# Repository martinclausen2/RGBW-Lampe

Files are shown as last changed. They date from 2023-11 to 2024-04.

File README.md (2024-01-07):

# RGBW-Lampe

The "RGBW-Lampe" projects allows to create full color lighting appliances.

## Features

- Four independent LED driver channels
  - Optimal to drive RGBW LED modules.
  - Mood light mode
  - High dynamic dimming range ideal for color mixing
- Status LED to indicate power on, channel, standby, and network status
- Brightness measurement to adjust brightness at power on
- IR remote control (receiver and sender)
  -	Option to network devices
- Single rotational encoder and switch needed to control
- Embedded terminal to control settings, clock, and alarms available via WLAN
  - Connect to home automation via MQTT
  - Adjust settings via exposed terminal
- Protected electronic power switch

## Technical Features
- ARM Cortex M3 based STM32L151A microcontroller
  - EEPROM for permanent storage of settings
- ESP8266 based WLAN connectivity ESP-12
- RC5 based communication (sender and receiver)
- Four PT4115 step-down LED driver
  - PWM input
  - LED driving current up to 1A
  - Short rise time of driving current to drive LED with very low duty PWM signals needed for color mixing
- Input voltage 9 to 15 V
- High dynamic brightness measurement with low cost phototransistor SFH320
- Pin header for observing and intercepting serial communication between MCU and WLAN module
  - Debugging
  - Initial programming of WLAN module
  - Redirecting communication to / from serial port of J-LINK
- PCB prepared (not used in current software) for 
  - Acceleration sensor
  - Pin headers for extension with additional I2C devices, LCD, or LED drivers
  - EEPROM from 24CXXX series with I2C connection - currently the MCU's internal EEPROM is utilized, the EEPROM can be populated if other STM32 MCU are to be used which do not contain a EEPROM

# Design description

## Hardware

### WLAN
The low cost WLAN module ESP-12 based on the ESP8266 is used to connect to home automation, expose an interface to configure the appliance, and to obtain date and time via NTP.

### MCU
The STM32L1 series features for this application relevant features like a large number of timers, and an embedded EEPROM.

The MCU can be programmed and debugged via SWD accessible through a custom pin header, that also exposes the serial port.

### LED Driver
Color mixing requires a large dimming range, which was realized via PWM dimming. The LED driver PT4115 has a short rise time allowing to create also very short current pulses to drive the LEDs at low levels.

### Logic Power Supply
A step down voltage regulator generates 3.3 V logic supply. It needs to be capable to provide good load regulation and sufficient current for the WLAN module as well as the IR-LED.

### RC5 receiver and sender

A IR emitting diode is driven by a small MOSFET from the PWM output of a timer in the MCU to send RC5 commands.

To receive RC5 commands the output of the IR receiver is sampled at a rate of about 4.5kHz by the MCU. The power supply of the IR receiver is cut in standby mode to prevent the battery to be drained prematurely.

### Brightness Sensor

The ambient brightness is sensed via an inexpensive and broadly available phototransistor SFA 320. To enhance the dynamic range, the MCU can switch the bias current between two different levels.
The precision is fully sufficient to adjust the brightness of the power LEDs at power on and dim the status LED in standby.

## Software

### WLAN Module

The time is fetched on start and about once per day later from the NTP server.

The terminal is exposed via port 22.

## Known Limitations
- The WLAN module may lose its connection when allowing Protected Management Frames (PMF) by the WLAN access point.
  - For Fritz!Box the option is found under WLAN -> Security -> Additional Security Settings
	 - German: Leave the option "Unterstützung für geschützte Anmeldungen von WLAN-Geräten (PMF) aktivieren" **unchecked**
- The WLAN module has fixed settings. Recompilation and flashing of the ESP8266 is needed to change them.
  - MQTT (device?.h)
  - WLAN (credentials.h)
  - NTP server (device?.h)
- The WLAN module exposes the ports of terminal (22) and MQTT without any protection.
- Commands received via MQTT and updates from the NTP server are injected into the terminal communication. Commands from the terminal might be interrupted by MQTT or time updates.
- OTA updates of the STM32 are not implemented yet.
- During power on, the LED driver operate at full current for a fraction of a second.

# User Manual

The user interface is rather simplistic.

Turning the encoder increases or decreases the brightness.
The integrated push button is used to select functionality and change between on and off.
Detailed settings can be adjusted via the serial terminal.

Coming from standby a short button press switches the light on. A long button press activates the networked mode, where other compatible lighting appliances receive commands to follow on, off, and brightness settings.

When the appliance in on the short button press selects between the four individual LED strings and a mode where the brightness is modulated between the channels.

When the button is pressed, the status led previews a for a short time the next selected functionality.

Standby can be reached via a long button pressed from power on mode.

| LED Color 	| Condition | Status | 
| :--- | :--- | :--- |
| red			| | standby  |
| white			| | power on |
| blue flashing | 1 flash, pause | WLAN module booting |
| blue flashing | 3 flash, pause | No time from NTP server obtained |
| green flash	| while adjusting brightness | maximum brightness reached |
| red flash		| while adjusting brightness | minimum brightness reached |
| white flash	| pressing the button short | selected white LED channel  |
| red flash		| pressing the button short | selected red LED channel |
| blue flash	| pressing the button short | selected blue LED channel |
| green flash	| pressing the button short | selected green LED channel |
| pink flash	| pressing the button short | selected mood light mode |
| green flash	| pressing the button very long | cancel button pressed |

The white flash is actually not visible, since the LED is already shining white.

# Configuration Manual

The serial port uses the following parameter 115200 Baud rate, data site 8, parity none, stop bits 1.

This terminal is exposed via the WLAN module to the user on port 22.

The commands can be listed by sending the command `help`.

## WLAN

WLAN credentials must be set at compile time in the file `credentials.h`.

## MQTT

Broker and node name must be defined at compile time in the file `device?.h`:

	#define MQTTbroker "192.168.178.123"
	#define nodename "RGBW-Lampe1"

Topics might be freely defined at compile time in the file `device?.h`. The following section contains some examples.

The appliance publishes to different topics its status:

	#define publishtopicstatus "RGBW-Lampe/1/status"
	#define publishtopicNTP "RGBW-Lampe/1/NTP"
	#define publishtopicswitch "RGBW-Lampe/1/switch"

The appliance subscribes to two topics defined at compile time in the file `device?.h`. The names are here choosen to be independent of the device id.

### MQTT to terminal forwarder

	#define subscribetopic "RGBW-Lampe"
All data is forwarded to the terminal of the MCU. See terminal section below for details.

### Switch

	#define subscribetopicswitch "RGBW-Lampe/switch"
The commands are `on` and `off`

## Commands Terminal

The terminal is accessible at three different routes:

- Interception of the serial WLAN - MCU communication through the pin header on the PCB
- Port 22 of the WLAN module
- MQTT topic defined by `subscribetopic`

### Set Brightness

	bright [type] <-c channel_no> <-b brightness_value>

set brightness values

| Type | Description |
| :--- | :--- |
| 0 | Brightness last used before lights were switched off. |
| 1 | Minimum brightness when switched on |
| 2 | Maximum brightness any time |
| 3 | Maximum brightness when an alarm is triggered |
| 4 | PWM offset for brightness |
| 5 | Current brightness |

### Get External Brightness

	getextbright

Get the external brightness from the phototransistor

### Infrared Remote Control

	remote <-a address> <-rm receiver mode> <-sm sender mode> <-sa send address> <-sd send data>

set infrared remote parameters

| Mode | Decription |
| :--- | :--- |
| 0 | Off |
| 1 | Alarm |
| 2 | Condional |
| 3 | All |

### Set Date and Time

	time [hour] [minute] [second]

set time of RTC

	date [2 digit year] [month] [day] [w] with w weekday

set date of RTC

	timestamp

get date and time from RTC

### Alarm

	alarmschedule [alarm no] <-w weekday> <-h hour> <-m minute>

set alarm schedule

	alarmsetting <-f time to fade-in light> <-si time to signal> <-sn snooze time>

set alarm parameters
	
	alarm <-a 1 | 0> <-s alarm skip count>

trigger, reset, set alarm skip count

### Beep

	beep <-s 1 | 0> volume - <-v volume> volume level - <-vl 1 | 0>

Call without any parameters to hear a beep. Using the `-s` parameter allows to turn the acoustic signal on and off. Volume allows for a continues selection of the volume between 0 and 255. The volume level sets the range in which the volume is adjustable.

### Power

	power <-l 1 | 0>

switch light.

### Reset Settings

	reset

reset settings to factory defaults

### Status LED

	statusled [flash count]

flash status led

### Mood light

	fadelight <-f 1 | 0> time - <-t time> <-b brightness> <-mb maximum brightness>

switch and parameterize on mood light

### DebugCmd

	debug

Dummy command to absorb debug messages from host.

### Reset WLAN Module

	resetesp

Reset network controller ESP8266.

### Version

	version

show STM32 software version

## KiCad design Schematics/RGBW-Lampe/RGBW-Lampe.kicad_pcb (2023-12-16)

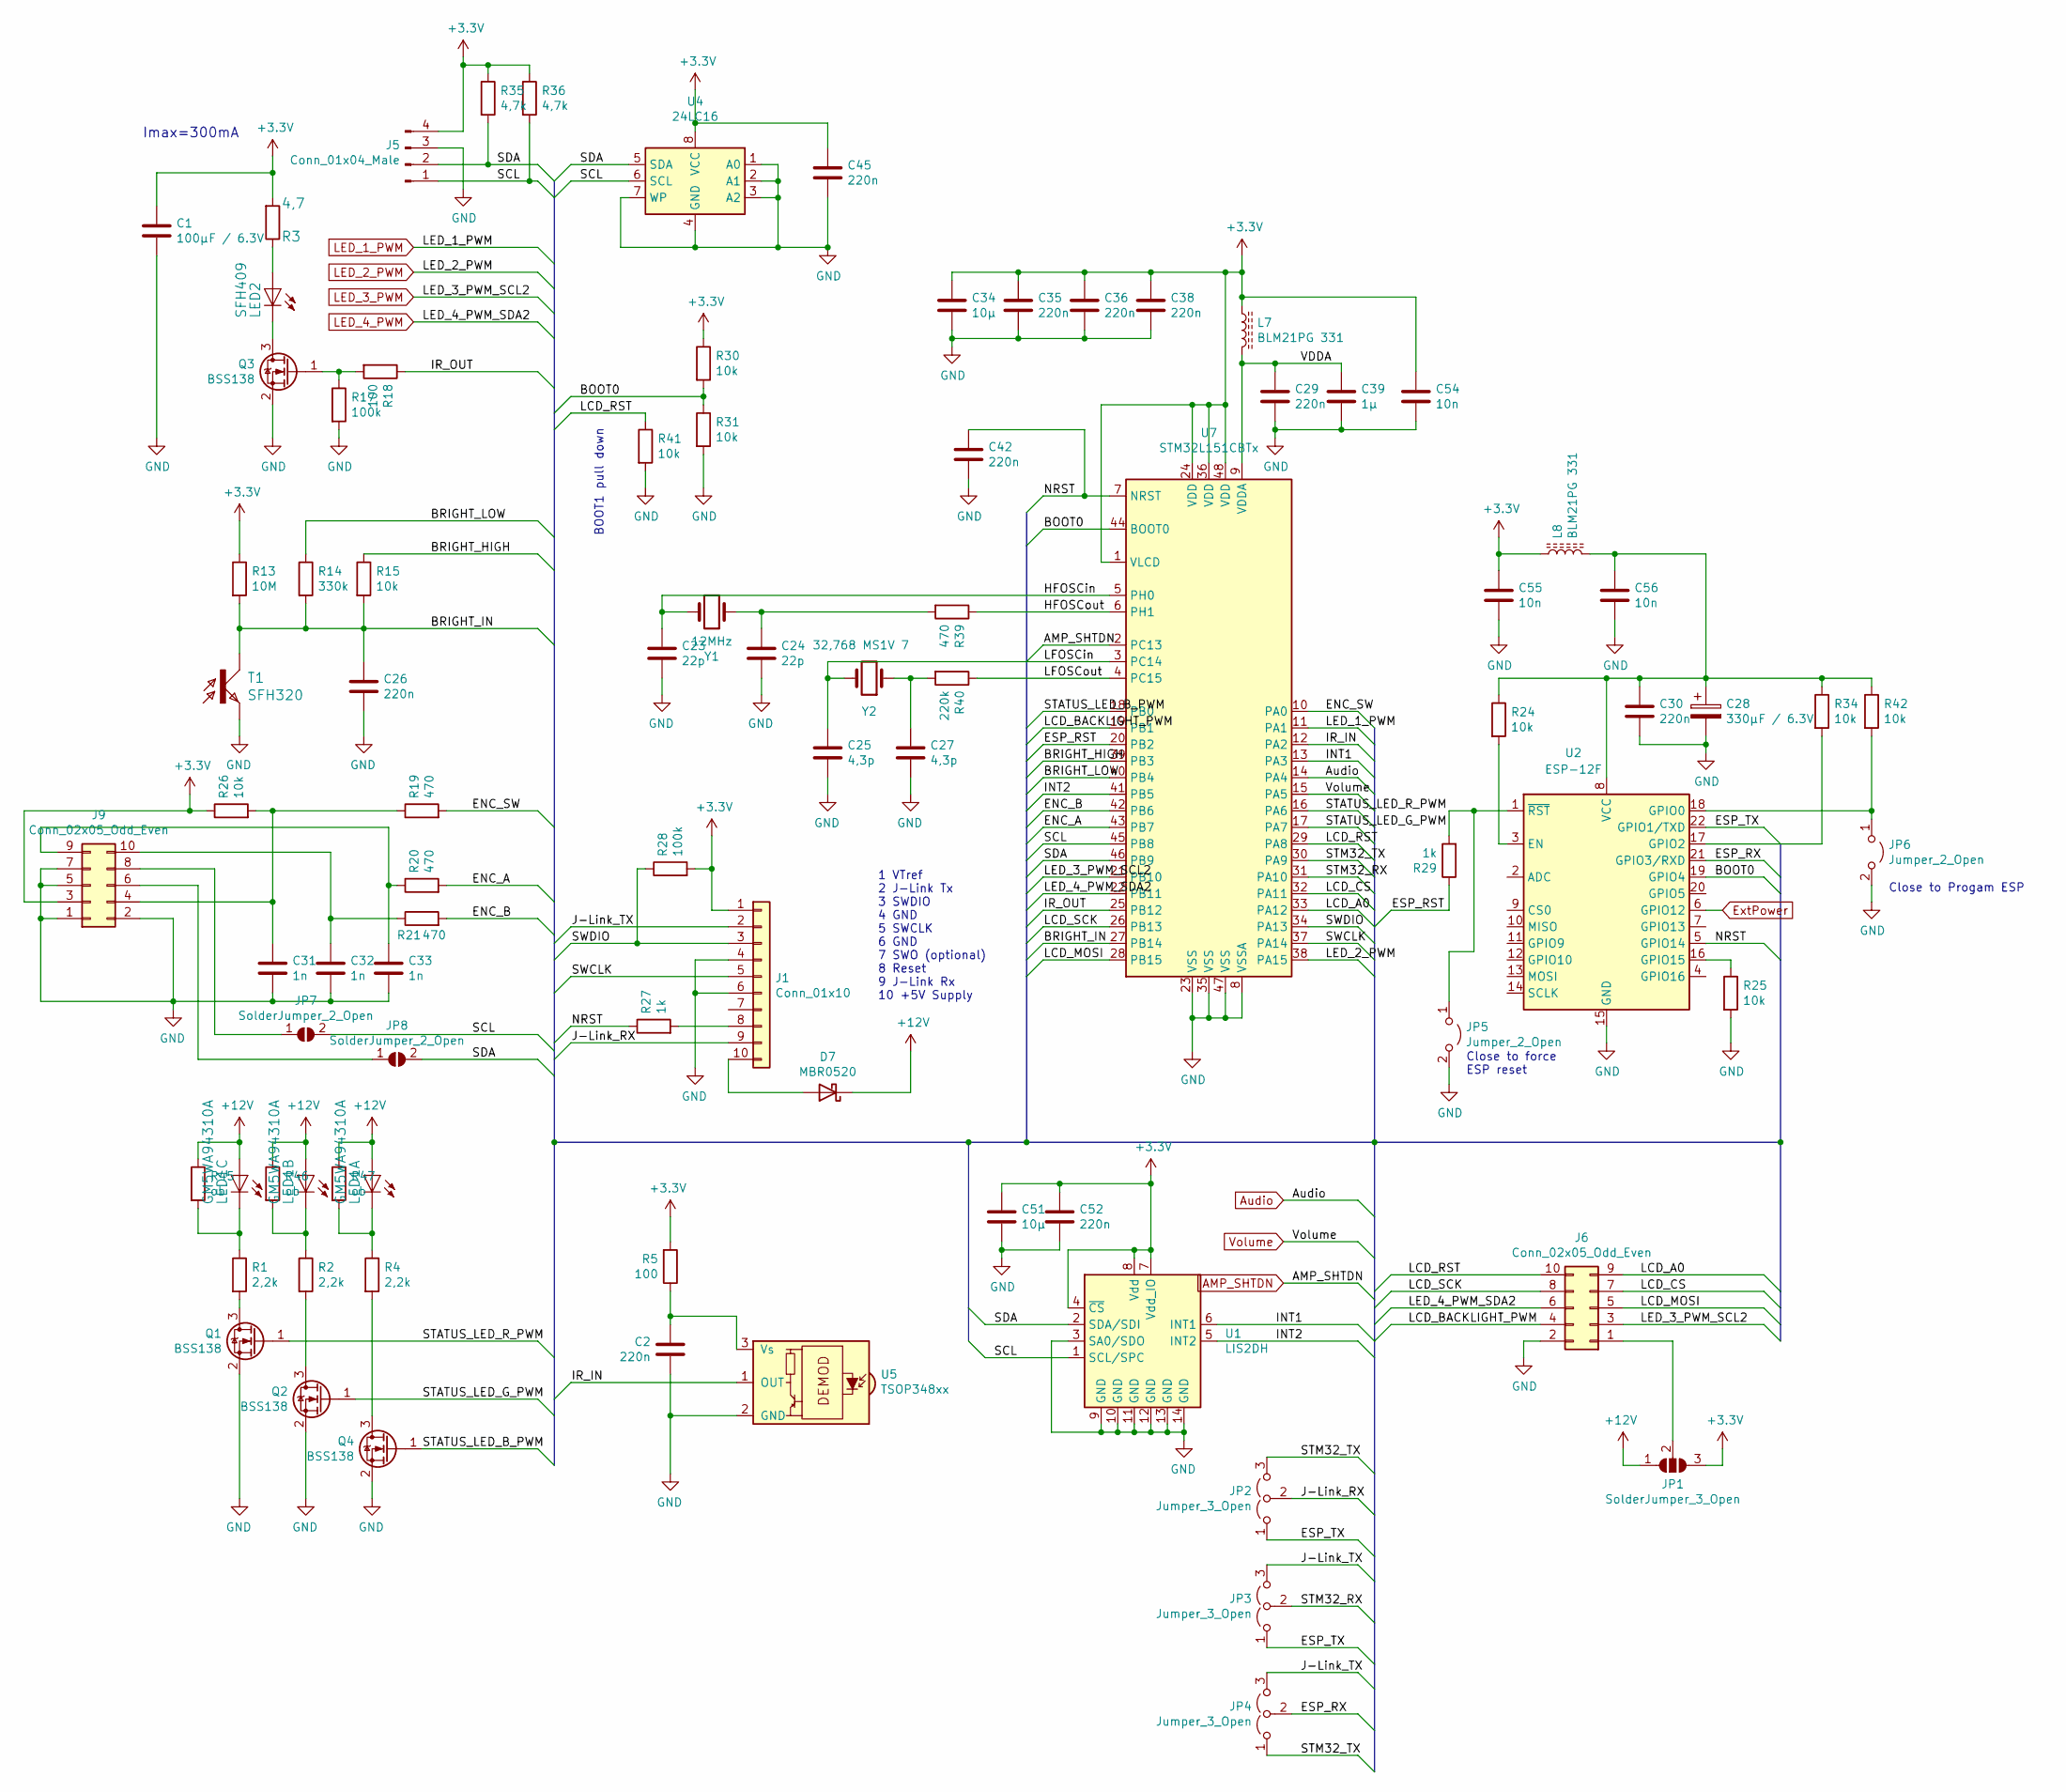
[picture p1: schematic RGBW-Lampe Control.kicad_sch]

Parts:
C1: 100µF / 6.3V; C_1210_3225Metric
C2, C26, C29, C30, C35, C36, C38, C42, C45, C52: 220n; C_0603_1608Metric
C23, C24: 22p; C_0603_1608Metric
C25, C27: 4,3p; C_0603_1608Metric
C28: 330µF / 6.3V; CP_Radial_D6.3mm_P2.50mm
C31, C32, C33: 1n; C_0603_1608Metric
C34, C51: 10µ; C_0805_2012Metric
C39: 1µ; C_0805_2012Metric
C54, C55, C56: 10n; C_0603_1608Metric
D7: MBR0520; D_SOD-123
J1: Conn_01x10; PinSocket_1x10_P1.27mm_Vertical
J5: Conn_01x04_Male; PinHeader_1x04_P2.54mm_Vertical
J6, J9: Conn_02x05_Odd_Even; IDC-Header_2x05_P2.54mm_Vertical
JP1: SolderJumper_3_Open; SolderJumper-3_P1.3mm_Open_RoundedPad1.0x1.5mm_NumberLabels
JP2, JP3, JP4: Jumper_3_Open; PinHeader_1x03_P2.54mm_Vertical
JP5, JP6: Jumper_2_Open; PinHeader_1x02_P2.54mm_Vertical
JP7, JP8: SolderJumper_2_Open; SolderJumper-2_P1.3mm_Open_Pad1.0x1.5mm
L7, L8: BLM21PG 331; L_0805_2012Metric
LED1: GM5WA94310A
LED2: SFH409; LED3MM
Q1, Q2, Q3, Q4: BSS138; SOT-23
R1, R2, R4: 2,2k; R_0805_2012Metric
R3: 4,7; R_1206_3216Metric
R5, R18: 100; R_0805_2012Metric
R13: 10M; R_0805_2012Metric
R14: 330k; R_0805_2012Metric
R15, R24, R25, R26, R30, R31, R34, R41, R42: 10k; R_0805_2012Metric
R17, R28: 100k; R_0805_2012Metric
R19, R20, R21, R39: 470; R_0805_2012Metric
R27, R29: 1k; R_0805_2012Metric
R35, R36: 4,7k; R_0805_2012Metric
R40: 220k; R_0805_2012Metric
R45, R46, R47: ob; R_0805_2012Metric
T1: SFH320; LED_PLCC-2
U1: LIS2DH; LGA-14_2x2mm_P0.35mm_LayoutBorder3x4y
U2: ESP-12F; ESP-12E
U4: 24LC16; SOIC-8_3.9x4.9mm_P1.27mm
U5: TSOP348xx; Vishay_MOLD-3Pin
U7: STM32L151CBTx; LQFP-48_7x7mm_P0.5mm
Y1: 12MHz; Crystal_SMD_EuroQuartz_MT-4Pin_3.2x2.5mm
Y2: 32,768 MS1V 7; Crystal_SMD_MicroCrystal_MS1V-T1K

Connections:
+3V3: C1.1, C34.1, C35.1, C36.1, C38.1, C45.1, C51.1, C52.1, C54.1, C55.1, J1.1, J5.4, J9.3, JP1.3 (B), L7.1, L8.1, R3.2, R5.2, R13.1, R26.1, R28.2, R30.1, R35.1, R36.1, U1.4 (~CS), U1.7 (Vdd_IO), U1.8 (Vdd), U4.8 (VCC), U7.1 (VLCD), U7.24 (VDD), U7.36 (VDD), U7.48 (VDD); also elsewhere on the board
+12V: D7.1 (K), JP1.1 (A), LED1.1 (A), LED1.2 (A), LED1.3 (A), R45.1, R46.1, R47.1; also elsewhere on the board
/Control/BOOT0: R30.2, R31.1, U2.19 (GPIO4), U7.44 (BOOT0)
/Control/BRIGHT_HIGH: R15.1, U7.39 (PB3)
/Control/BRIGHT_IN: C26.1, R13.2, R14.2, R15.2, T1.1 (C), U7.27 (PB14)
/Control/BRIGHT_LOW: R14.1, U7.40 (PB4)
/Control/ENC_A: R20.2, U7.43 (PB7)
/Control/ENC_B: R21.2, U7.42 (PB6)
/Control/ENC_SW: R19.2, U7.10 (PA0)
/Control/ESP_RST: R29.1, U7.20 (PB2)
/Control/ESP_RX: JP4.2 (C), U2.21 (GPIO3/RXD)
/Control/ESP_TX: JP2.1 (A), JP3.1 (A), U2.22 (GPIO1/TXD)
/Control/HFOSCin: C23.1, U7.5 (PH0), Y1.2
/Control/HFOSCout: R39.1, U7.6 (PH1)
/Control/INT1: U1.6 (INT1), U7.13 (PA3)
/Control/INT2: U1.5 (INT2), U7.41 (PB5)
/Control/IR_IN: U5.1 (OUT), U7.12 (PA2)
/Control/IR_OUT: R18.1, U7.25 (PB12)
/Control/J-Link_RX: J1.9, JP2.2 (C)
/Control/J-Link_TX: J1.2, JP3.3 (B), JP4.3 (B)
/Control/LCD_A0: J6.9, U7.33 (PA12)
/Control/LCD_BACKLIGHT_PWM: J6.4, U7.19 (PB1)
/Control/LCD_CS: J6.7, U7.32 (PA11)
/Control/LCD_MOSI: J6.5, U7.28 (PB15)
/Control/LCD_RST: J6.10, R41.1, U7.29 (PA8)
/Control/LCD_SCK: J6.8, U7.26 (PB13)
/Control/LFOSCin: C25.1, U7.3 (PC14), Y2.2
/Control/LFOSCout: R40.1, U7.4 (PC15)
/Control/NRST: C42.1, R27.1, U2.5 (GPIO14), U7.7 (NRST)
/Control/SCL: J5.1, JP7.2 (B), R36.2, U1.1 (SCL/SPC), U4.6 (SCL), U7.45 (PB8)
/Control/SDA: J5.2, JP8.2 (B), R35.2, U1.2 (SDA/SDI), U4.5 (SDA), U7.46 (PB9)
/Control/STATUS_LED_B_PWM: Q4.1 (G), U7.18 (PB0)
/Control/STATUS_LED_G_PWM: Q2.1 (G), U7.17 (PA7)
/Control/STATUS_LED_R_PWM: Q1.1 (G), U7.16 (PA6)
/Control/STM32_RX: JP3.2 (C), U7.31 (PA10)
/Control/STM32_TX: JP2.3 (B), JP4.1 (A), U7.30 (PA9)
/Control/SWCLK: J1.5, U7.37 (PA14)
/Control/SWDIO: J1.3, R28.1, U7.34 (PA13)
/Control/VDDA: C29.1, C39.1, L7.2, U7.9 (VDDA)
AMP_SHTDN: U7.2 (PC13); also elsewhere on the board
Audio: U7.14 (PA4); also elsewhere on the board
ExtPower: U2.6 (GPIO12); also elsewhere on the board
GND: C1.2, C2.2, C23.2, C24.2, C25.2, C26.2, C27.2, C28.2, C29.2, C30.2, C31.2, C32.2, C33.2, C34.2, C35.2, C36.2, C38.2, C39.2, C42.2, C45.2, C51.2, C52.2, C54.2, C55.2, C56.2, J1.4, J1.6, J5.3, J6.2, J9.1, J9.2, J9.5, J9.7, JP5.2 (B), JP6.2 (B), Q1.2 (S), Q2.2 (S), Q3.2 (S), Q4.2 (S), R17.2, R25.2, R31.2, R41.2, T1.2 (E), U1.3 (SA0/SDO), U1.9 (GND), U1.10 (GND), U1.11 (GND), U1.12 (GND), U1.13 (GND), U1.14 (GND), U2.15 (GND), U4.1 (A0), U4.2 (A1), U4.3 (A2), U4.4 (GND), U4.7 (WP), U5.2 (GND), U7.8 (VSSA), U7.23 (VSS), U7.35 (VSS), U7.47 (VSS); also elsewhere on the board
LED_1_PWM: U7.11 (PA1); also elsewhere on the board
LED_2_PWM: U7.38 (PA15); also elsewhere on the board
LED_3_PWM: J6.3, U7.21 (PB10); also elsewhere on the board
LED_4_PWM: J6.6, U7.22 (PB11); also elsewhere on the board
unnamed: C2.1, R5.1, U5.3 (Vs)
unnamed: C24.1, R39.2, Y1.1
unnamed: C27.1, R40.2, Y2.1
unnamed: C28.1, C30.1, C56.1, L8.2, R24.1, R34.1, R42.1, U2.8 (VCC)
unnamed: C31.1, J9.4, R19.1, R26.2
unnamed: C32.1, J9.10, R21.1
unnamed: C33.1, J9.9, R20.1
unnamed: D7.2 (A), J1.10
unnamed: J1.8, R27.2
unnamed: J6.1, JP1.2 (C)
unnamed: J9.6, JP8.1 (A)
unnamed: J9.8, JP7.1 (A)
unnamed: JP5.1 (A), R29.2, U2.1 (~RST)
unnamed: JP6.1 (A), R42.2, U2.18 (GPIO0)
unnamed: LED1.4 (C), R2.1, R46.2
unnamed: LED1.5 (C), R4.1, R47.2
unnamed: LED1.6 (C), R1.1, R45.2
unnamed: LED2.A, R3.1
unnamed: LED2.K (C), Q3.3 (D)
unnamed: Q1.3 (D), R1.2
unnamed: Q2.3 (D), R2.2
unnamed: Q3.1 (G), R17.1, R18.2
unnamed: Q4.3 (D), R4.2
unnamed: R24.2, U2.3 (EN)
unnamed: R25.1, U2.16 (GPIO15)
unnamed: R34.2, U2.17 (GPIO2)
Volume: U7.15 (PA5); also elsewhere on the board

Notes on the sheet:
BOOT1 pull down
1 VTref 2 J-Link Tx 3 SWDIO 4 GND 5 SWCLK 6 GND 7 SWO (optional) 8 Reset 9 J-Link Rx 10 +5V Supply
Close to Progam ESP
Imax=300mA
Close to force ESP reset

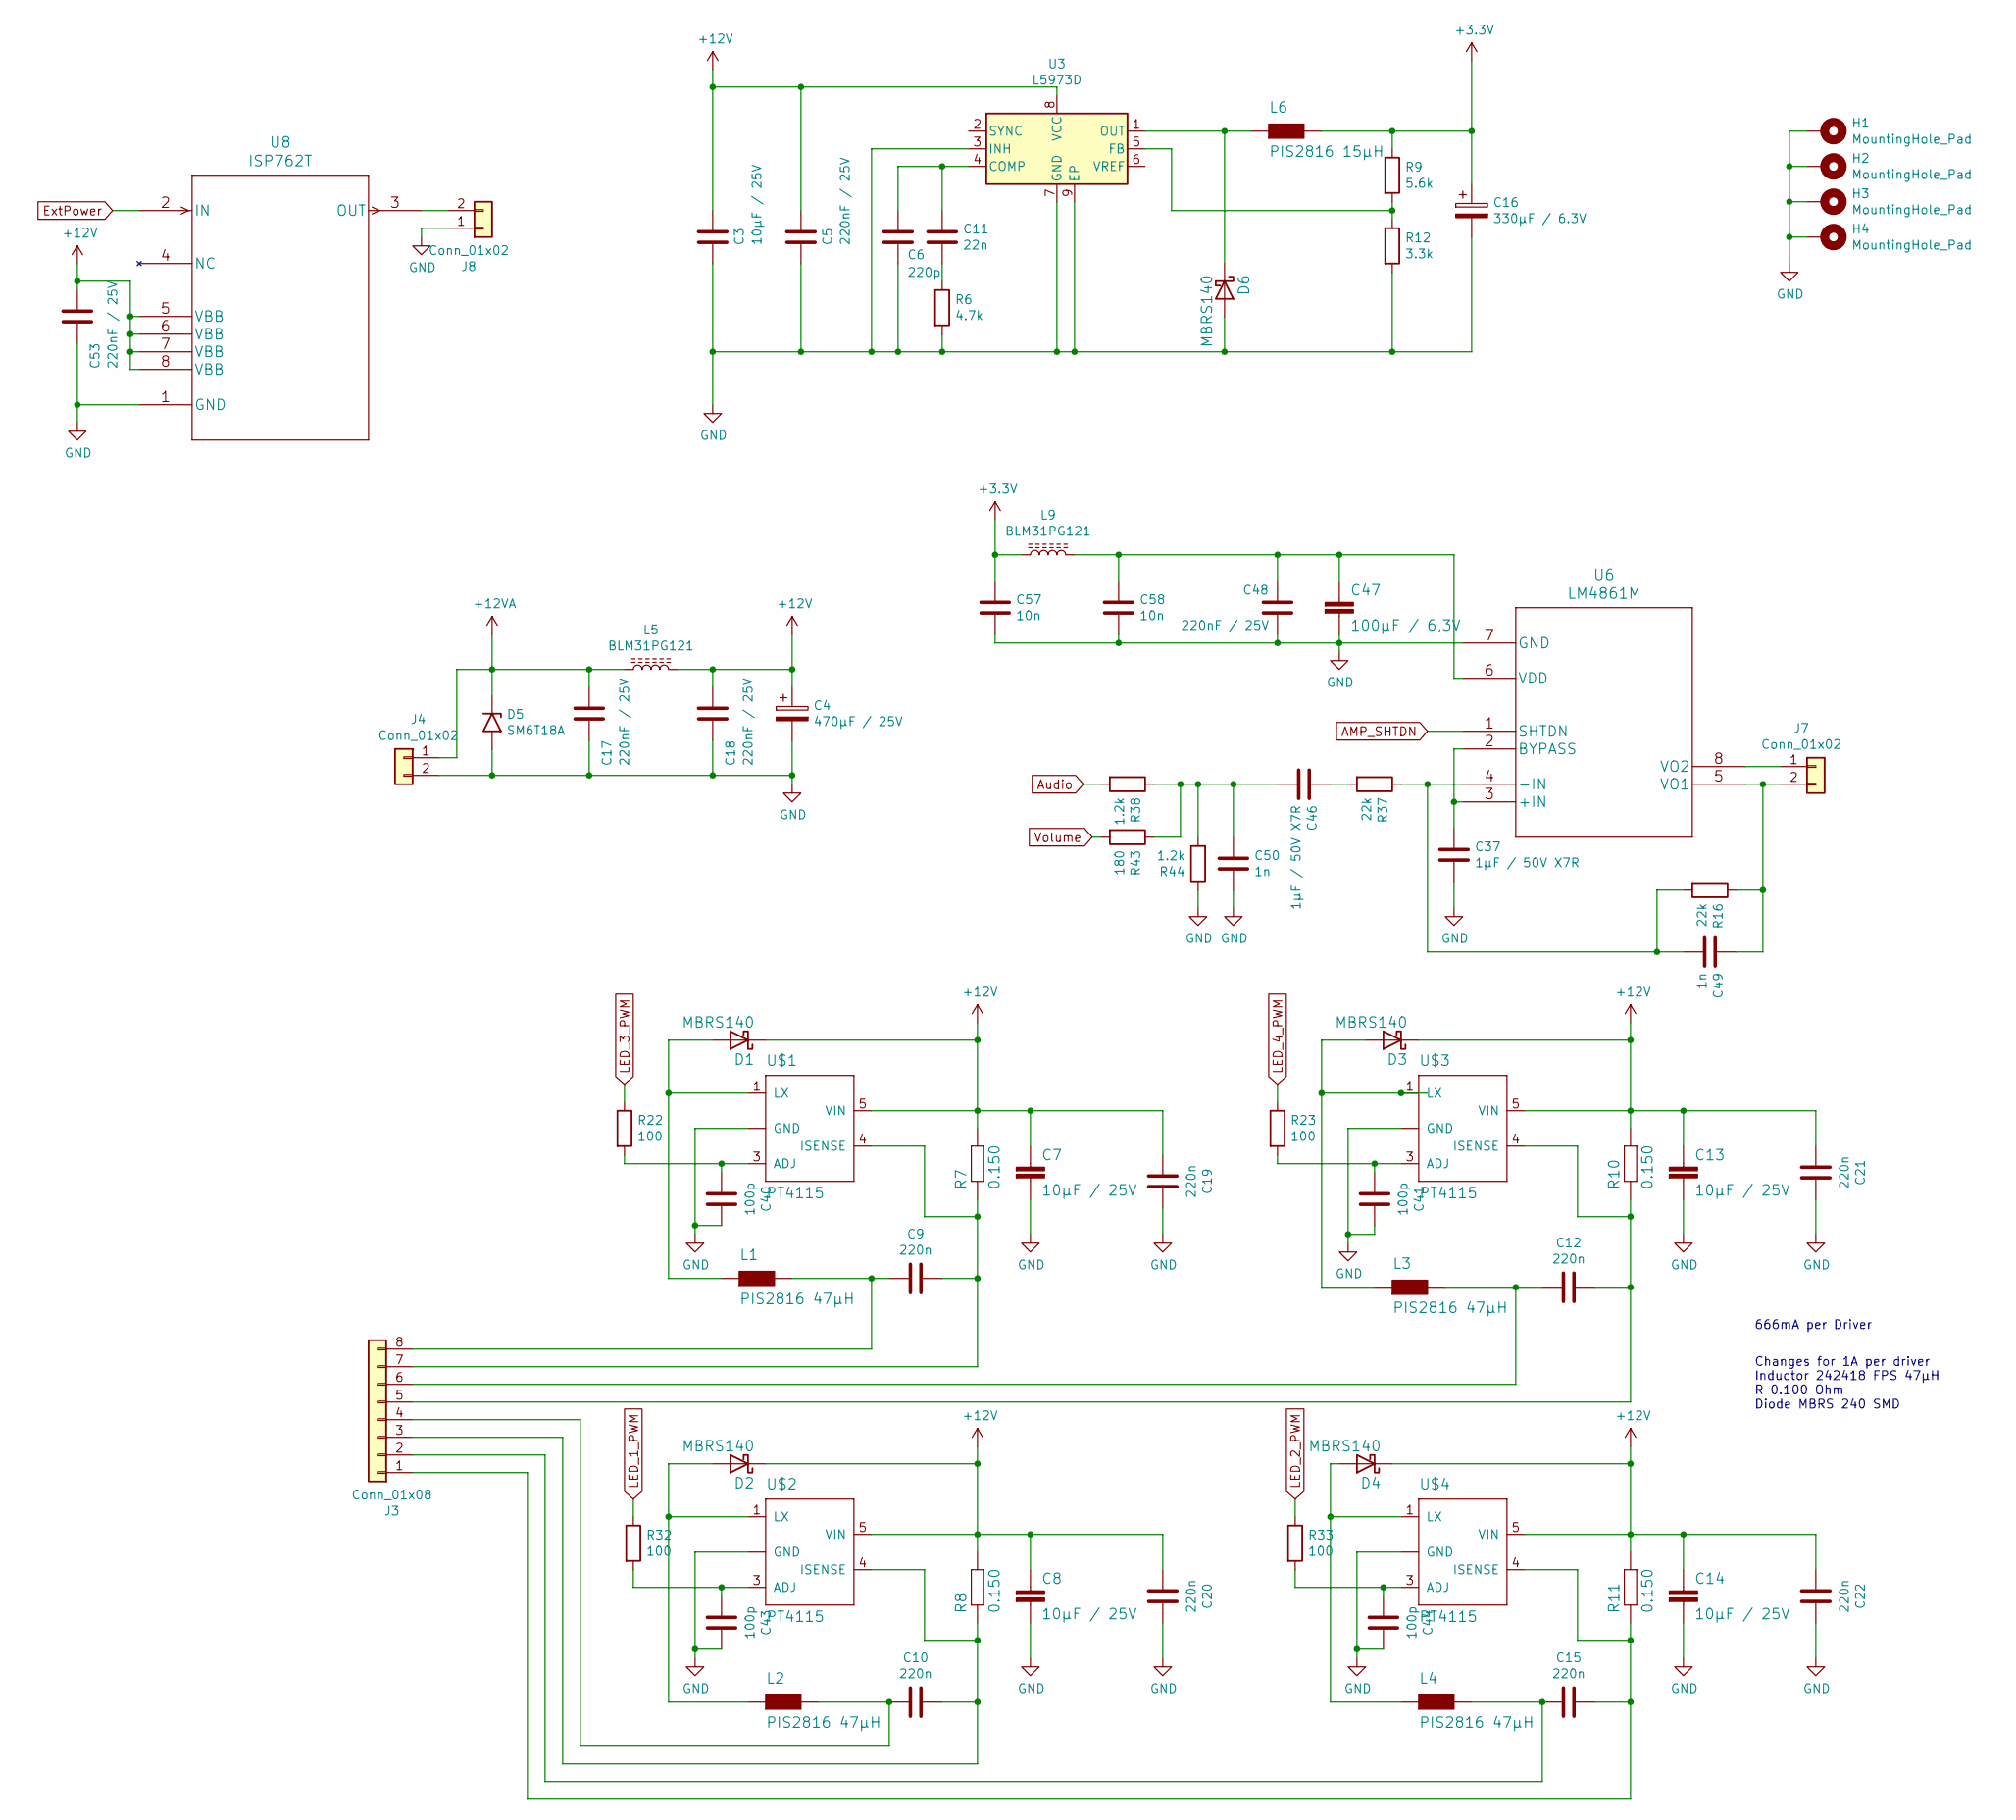
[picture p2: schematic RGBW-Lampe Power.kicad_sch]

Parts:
C3, C7, C8, C13, C14: 10µF / 25V; C_1206_3216Metric
C4: 470µF / 25V; CP_Radial_D8.0mm_P3.50mm
C5, C17, C18, C48, C53: 220nF / 25V; C_0603_1608Metric
C6: 220p; C_0603_1608Metric
C9, C10, C12, C15, C19, C20, C21, C22: 220n; C_0603_1608Metric
C11: 22n; C_0603_1608Metric
C16: 330µF / 6.3V; CP_Radial_D6.3mm_P2.50mm
C37, C46: 1µF / 50V X7R; C_1206_3216Metric
C40, C41, C43, C44: 100p; C_0603_1608Metric
C47: 100µF / 6,3V; C_1206_3216Metric
C49, C50: 1n; C_0603_1608Metric
C57, C58: 10n; C_0603_1608Metric
D1, D2, D3, D4, D6: MBRS140; D_SMB
D5: SM6T18A; D_SMB
H1, H2, H3, H4: MountingHole_Pad; MountingHole_3.2mm_M3_DIN965_Pad
J3: Conn_01x08; JST_XH_B8B-XH-A_1x08_P2.50mm_Vertical
J4, J7, J8: Conn_01x02; JST_XH_B2B-XH-A_1x02_P2.50mm_Vertical
L1, L2, L3, L4: PIS2816 47µH; PIS2816
L5, L9: BLM31PG121; L_1206_3216Metric
L6: PIS2816 15µH; PIS2816
R6: 4.7k; R_0805_2012Metric
R7, R8, R10, R11: 0.150; R_1210_3225Metric
R9: 5.6k; R_0805_2012Metric
R12: 3.3k; R_0805_2012Metric
R16, R37: 22k; R_0805_2012Metric
R22, R23, R32, R33: 100; R_0805_2012Metric
R38, R44: 1.2k; R_0805_2012Metric
R43: 180; R_0805_2012Metric
U3: L5973D; HSOP-8-1EP_3.9x4.9mm_P1.27mm_EP2.41x3.1mm_ThermalVias
U6: LM4861M
U8: ISP762T
U$1, U$2, U$3, U$4: PT4115; SOT89-5

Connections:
+3V3: C16.1, C57.2, L6.P$2, L9.1, R9.1; also elsewhere on the board
+12V: C3.1, C4.1, C5.2, C7.1, C8.1, C13.1, C14.1, C18.2, C19.2, C20.2, C21.2, C22.2, C53.2, D1.1 (K), D2.1 (K), D3.1 (K), D4.1 (K), L5.2, R7.2, R8.2, R10.2, R11.2, U3.8 (VCC), U8.5 (VBB), U8.6 (VBB), U8.7 (VBB), U8.8 (VBB), U$1.5 (VIN), U$2.5 (VIN), U$3.5 (VIN), U$4.5 (VIN); also elsewhere on the board
+12VA: C17.2, D5.1 (A1), J4.1, L5.1
AMP_SHTDN: U6.1 (SHTDN); also elsewhere on the board
Audio: R38.2; also elsewhere on the board
ExtPower: U8.2 (IN); also elsewhere on the board
GND: C3.2, C4.2, C5.1, C6.2, C7.2, C8.2, C13.2, C14.2, C16.2, C17.1, C18.1, C19.1, C20.1, C21.1, C22.1, C37.2, C40.1, C41.1, C43.1, C44.1, C47.2, C48.1, C50.1, C53.1, C57.1, C58.1, D5.2 (A2), D6.2 (A), H1.1, H2.1, H3.1, H4.1, J4.2, J8.1, R6.2, R12.2, R44.1, U3.3 (INH), U3.7 (GND), U3.9 (EP), U6.7 (GND), U8.1 (GND), U$1.2 (GND), U$1.2.1 (GND), U$2.2 (GND), U$2.2.1 (GND), U$3.2 (GND), U$3.2.1 (GND), U$4.2 (GND), U$4.2.1 (GND); also elsewhere on the board
LED_1_PWM: R32.1; also elsewhere on the board
LED_2_PWM: R33.1; also elsewhere on the board
LED_3_PWM: R22.1; also elsewhere on the board
LED_4_PWM: R23.1; also elsewhere on the board
unnamed: C9.1, J3.7, R7.1, U$1.4 (ISENSE)
unnamed: C9.2, J3.8, L1.P$2
unnamed: C10.1, J3.3, R8.1, U$2.4 (ISENSE)
unnamed: C10.2, J3.4, L2.P$2
unnamed: C6.1, C11.1, U3.4 (COMP)
unnamed: C11.2, R6.1
unnamed: C12.1, J3.5, R10.1, U$3.4 (ISENSE)
unnamed: C12.2, J3.6, L3.P$2
unnamed: C15.1, J3.1, R11.1, U$4.4 (ISENSE)
unnamed: C15.2, J3.2, L4.P$2
unnamed: C37.1, U6.2 (BYPASS), U6.3 (+IN)
unnamed: C40.2, R22.2, U$1.3 (ADJ)
unnamed: C41.2, R23.2, U$3.3 (ADJ)
unnamed: C43.2, R32.2, U$2.3 (ADJ)
unnamed: C44.2, R33.2, U$4.3 (ADJ)
unnamed: C46.1, R37.2
unnamed: C46.2, C50.2, R38.1, R43.1, R44.2
unnamed: C47.1, C48.2, C58.2, L9.2, U6.6 (VDD)
unnamed: C49.1, R16.2, R37.1, U6.4 (-IN)
unnamed: C49.2, J7.2, R16.1, U6.5 (VO1)
unnamed: D1.2 (A), L1.P$1, U$1.1 (LX)
unnamed: D2.2 (A), L2.P$1, U$2.1 (LX)
unnamed: D3.2 (A), L3.P$1, U$3.1 (LX)
unnamed: D4.2 (A), L4.P$1, U$4.1 (LX)
unnamed: D6.1 (K), L6.P$1, U3.1 (OUT)
unnamed: J7.1, U6.8 (VO2)
unnamed: J8.2, U8.3 (OUT)
unnamed: R9.2, R12.1, U3.5 (FB)
Volume: R43.2; also elsewhere on the board

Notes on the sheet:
Changes for 1A per driver Inductor 242418 FPS 47µH R 0.100 Ohm Diode MBRS 240 SMD
666mA per Driver

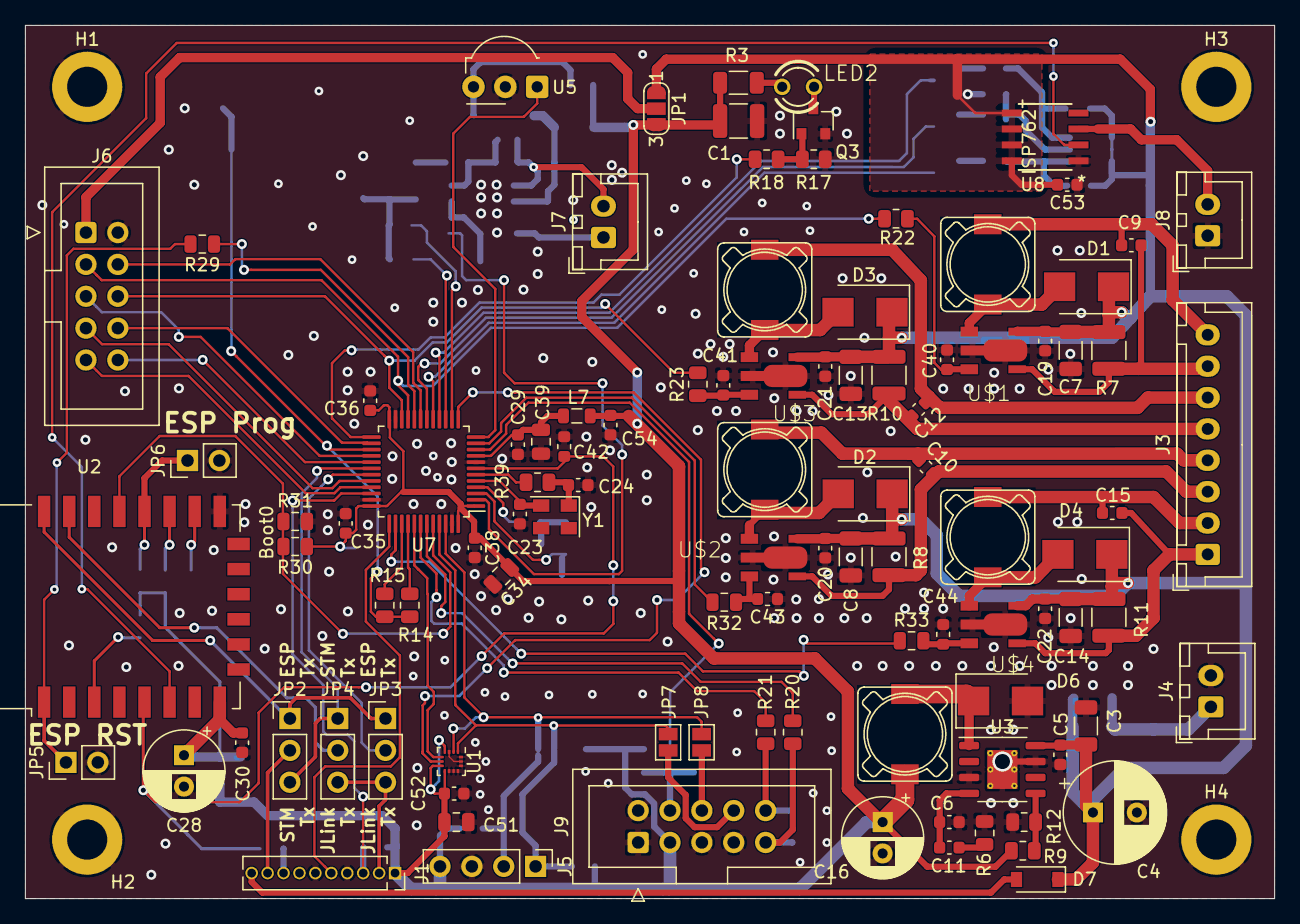
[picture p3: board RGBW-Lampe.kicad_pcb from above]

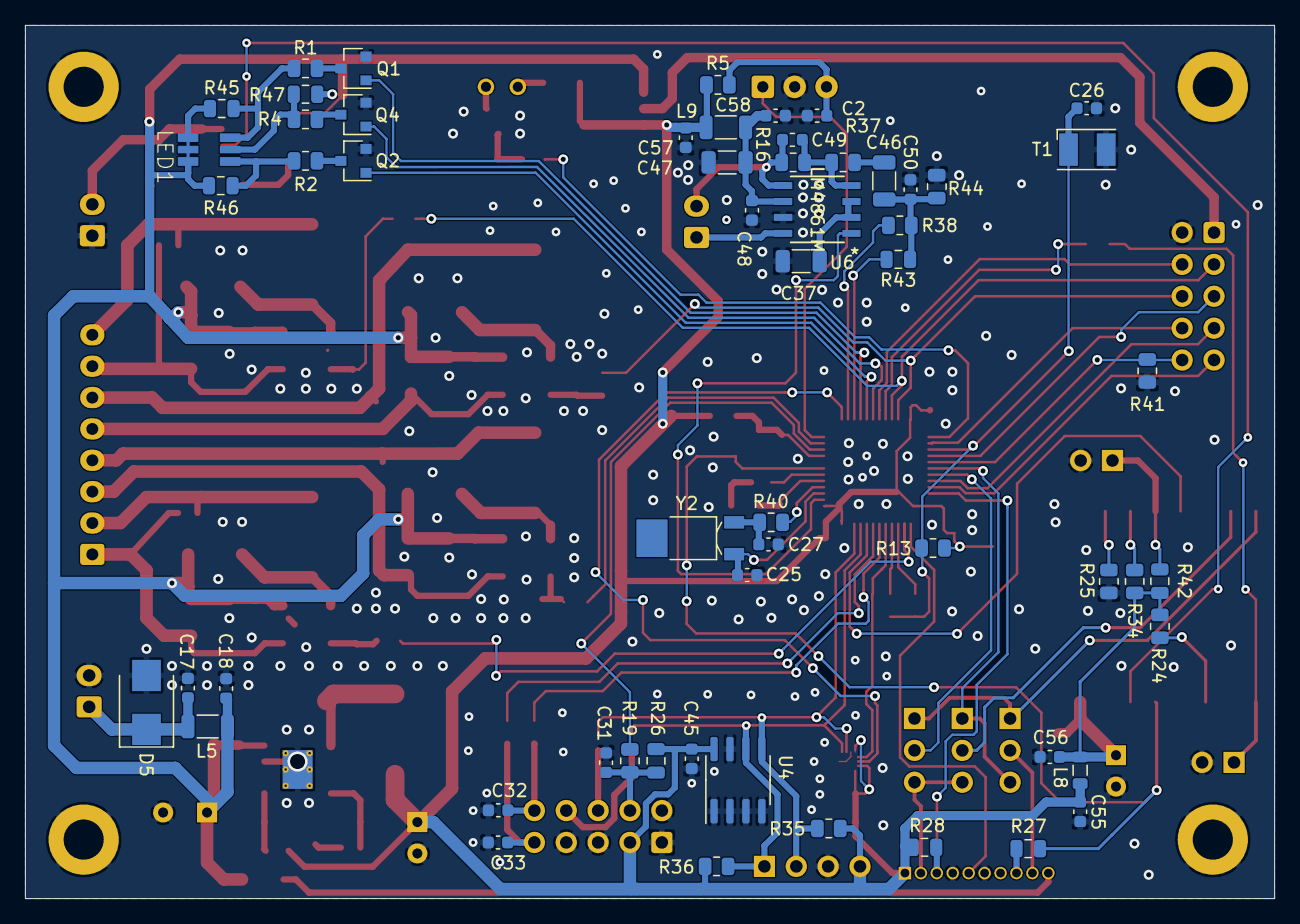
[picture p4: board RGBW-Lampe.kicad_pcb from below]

Board: 2 copper layers, 99.6 x 69.6 mm, 162 parts (57 on the bottom side), 103 nets.

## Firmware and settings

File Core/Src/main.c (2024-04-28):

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
/* Includes ------------------------------------------------------------------*/
#include "main.h"

ADC_HandleTypeDef hadc;

CRC_HandleTypeDef hcrc;

DAC_HandleTypeDef hdac;
DMA_HandleTypeDef hdma_dac_ch1;

I2C_HandleTypeDef hi2c1;

RTC_HandleTypeDef hrtc;

SPI_HandleTypeDef hspi2;

TIM_HandleTypeDef htim2;
TIM_HandleTypeDef htim3;
TIM_HandleTypeDef htim4;
TIM_HandleTypeDef htim6;
TIM_HandleTypeDef htim7;
TIM_HandleTypeDef htim9;
TIM_HandleTypeDef htim10;
TIM_HandleTypeDef htim11;

UART_HandleTypeDef huart1;
DMA_HandleTypeDef hdma_usart1_rx;
DMA_HandleTypeDef hdma_usart1_tx;

/* USER CODE BEGIN PV */
bool volatile TimerFlag;
/* USER CODE END PV */

void SystemClock_Config(void);
static void MX_GPIO_Init(void);
static void MX_DMA_Init(void);
static void MX_ADC_Init(void);
static void MX_DAC_Init(void);
static void MX_I2C1_Init(void);
static void MX_SPI2_Init(void);
static void MX_TIM2_Init(void);
static void MX_TIM3_Init(void);
static void MX_TIM4_Init(void);
static void MX_TIM9_Init(void);
static void MX_USART1_UART_Init(void);
static void MX_RTC_Init(void);
static void MX_TIM11_Init(void);
static void MX_TIM6_Init(void);
static void MX_CRC_Init(void);
static void MX_TIM7_Init(void);
static void MX_TIM10_Init(void);
/* USER CODE BEGIN PFP */
#define PUTCHAR_PROTOTYPE int __io_putchar(int ch)
/* USER CODE END PFP */

/**
  * @brief  The application entry point.
  * @retval int
  */
int main(void)
{

  /* MCU Configuration--------------------------------------------------------*/

  /* Reset of all peripherals, Initializes the Flash interface and the Systick. */
  HAL_Init();

  /* Configure the system clock */
  SystemClock_Config();

  /* Initialize all configured peripherals */
  MX_GPIO_Init();
  MX_DMA_Init();
  MX_ADC_Init();
  MX_DAC_Init();
  MX_I2C1_Init();
  MX_SPI2_Init();
  MX_TIM2_Init();
  MX_TIM3_Init();
  MX_TIM4_Init();
  MX_TIM9_Init();
  MX_USART1_UART_Init();
  MX_RTC_Init();
  MX_TIM11_Init();
  MX_TIM6_Init();
  MX_CRC_Init();
  MX_TIM7_Init();
  MX_TIM10_Init();
  /* USER CODE BEGIN 2 */
  	// DMA: UART, DAC
  	// ADC: external brightness
    // DAC: acoustic alarm signal generation
    // I2C1: acceleration sensor (planned)
    // SPI2: display (planned)
  	// TIM2: LED PWM
  	// TIM3: status LED PWM
    // TIM4: rotational encoder
	// TIM6: RC5 decoder timing
	// TIM7: acoustic alarm signal generation
    // TIM9: alternative RC5 decoder (planned)
    // TIM10: RC5 sender
    // TIM11: main control loop
    // USART1: terminal
    // CRC: EEPROM change check

	//load RAM values from EEPROM
	SettingsInit(&hcrc);

	Init_Terminal(&huart1);
	SettingsCommands_Init();
	Rtc_Init();
	PWM_Init(&htim2);
	Status_LED_Init(&htim3);
	Encoder_Init(&htim4);
	Init_ExtBrightness(&hadc);
	Init_FadeLight();
	RC5_Init(&htim6, &htim10);

	/*##-1- Start the TIM Base generation in interrupt mode ####################*/
	pTIM_CallbackTypeDef pMainTimerCallback = *MainTimerCallback;
	HAL_TIM_RegisterCallback(&htim11, HAL_TIM_PERIOD_ELAPSED_CB_ID, pMainTimerCallback);
	HAL_TIM_Base_Start_IT(&htim11); //main control loop

	SwAllLightOn();
  /* USER CODE END 2 */

  /* Infinite loop */
  /* USER CODE BEGIN WHILE */
	while (1)
	{
		if(TimerFlag)
		{
			TimerFlag=0;
			Keys(!HAL_GPIO_ReadPin(ENC_SW_GPIO_Port, ENC_SW_Pin));
			Encoder();
			MainMenu();
			Sample_ExtBrightness();
			LEDOptions();
		}
		Execute_Terminal();
		HAL_PWR_EnterSLEEPMode(PWR_MAINREGULATOR_ON, PWR_SLEEPENTRY_WFI);
    /* USER CODE END WHILE */

    /* USER CODE BEGIN 3 */
	}
  /* USER CODE END 3 */
}

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
/* USER CODE BEGIN 4 */

/*
 * @brief  Period elapsed callback in non blocking mode
 * @param  htim: TIM handle
 * @retval None
 */
void MainTimerCallback(TIM_HandleTypeDef *htim)
{
	//set flag, should be set at a frequency of 100Hz
	TimerFlag = true;
}

/* USER CODE END 4 */
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


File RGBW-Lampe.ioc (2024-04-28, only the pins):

Mcu.UserName=STM32L151CBTxA
PA0-WKUP1.GPIO_Label=ENC_SW
PA0-WKUP1.Signal=GPIO_Input
PA1.GPIO_Label=LED_2_PWM
PA1.Signal=S_TIM2_CH2
PA10.Signal=USART1_RX
PA11.GPIO_Label=LCD_CS
PA11.Signal=GPIO_Output
PA12.GPIO_Label=LCD_A0
PA12.Signal=GPIO_Output
PA13.Signal=SYS_JTMS-SWDIO
PA14.Signal=SYS_JTCK-SWCLK
PA15.GPIO_Label=LED_1_PWM
PA15.Signal=S_TIM2_CH1_ETR
PA2.GPIO_Label=IR_IN
PA2.Signal=S_TIM9_CH1
PA4.GPIO_Label=Audio
PA4.Signal=COMP_DAC1_group
PA5.GPIO_Label=Volume
PA5.Signal=GPIO_Output
PA6.GPIO_Label=STATUS_LED_R_PWM
PA6.Signal=S_TIM3_CH1
PA7.GPIO_Label=STATUS_LED_G_PWM
PA7.Signal=S_TIM3_CH2
PA8.GPIO_Label=LCD_RST
PA8.Signal=GPIO_Output
PA9.Signal=USART1_TX
PB0.GPIO_Label=STATUS_LED_B_PWM
PB0.Signal=S_TIM3_CH3
PB1.GPIO_Label=LCD_BACKLIGHT_PWM
PB1.Signal=S_TIM3_CH4
PB10.GPIO_Label=LED_3_PWM_SCL2
PB10.Signal=S_TIM2_CH3
PB11.GPIO_Label=LED_4_PWM_SDA2
PB11.Signal=S_TIM2_CH4
PB12.GPIO_Label=IR_OUT
PB12.Signal=S_TIM10_CH1
PB13.GPIO_Label=LCD_SCK
PB13.Signal=SPI2_SCK
PB14.GPIO_Label=BRIGHT_IN
PB14.Signal=ADC_IN20
PB15.GPIO_Label=LCD_MOSI
PB15.Signal=SPI2_MOSI
PB2.GPIO_Label=ESP_RST
PB2.Signal=GPIO_Output
PB3.GPIO_Label=BRIGHT_HIGH
PB3.Signal=GPIO_Output
PB4.GPIO_Label=BRIGHT_LOW
PB4.Signal=GPIO_Output
PB6.GPIO_Label=ENC_B
PB6.Signal=S_TIM4_CH1
PB7.GPIO_Label=ENC_A
PB7.Signal=S_TIM4_CH2
PB8.Signal=I2C1_SCL
PB9.Signal=I2C1_SDA
PC13-WKUP2.GPIO_Label=AMP_SHTDN
PC13-WKUP2.Signal=GPIO_Output
PC14-OSC32_IN.Signal=RCC_OSC32_IN
PC15-OSC32_OUT.Signal=RCC_OSC32_OUT
PH0-OSC_IN.Signal=RCC_OSC_IN
PH1-OSC_OUT.Signal=RCC_OSC_OUT

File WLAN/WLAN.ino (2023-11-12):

#include <ESP8266WiFi.h>
#include <ESP8266mDNS.h>
#include <WiFiUdp.h>
#include "EspMQTTClient.h"
#include <WiFiClient.h>
#include <Ticker.h>
#include <TimeLib.h>
#include <NTPClient.h>
#include "credentials.h" // not part of the git repository due to confidential information, please create you own file to inject the WIFI credetials or exclude this line and add them delow

#ifndef STASSID
#define STASSID "myWLAN"
#define STAPSK "secret"
#endif

// please adjust the following file for your environment
#include "device1.h"
#define version "6"

#define switchGPIO 12

// Error messages send to STM32
// 1 flash => booting
// 2 flash => no WLAN connection
// 3 flash => no NTP

#define UART_BAUD 115200
#define UART_PORT 22
#define packTimeout 5 // ms (if nothing more on UART, then send packet)
#define bufferSize 8192

#define NTPTimeCount 80000000 // connect about every 24 hours

const int uart_port = UART_PORT;

EspMQTTClient client(
  STASSID,
  STAPSK,
  MQTTbroker, // MQTT Broker server ip
  nodename    // Client name that uniquely identify your device
);

WiFiServer server(uart_port);
WiFiClient UARTclient;

uint8_t buf1[bufferSize];
uint16_t i1=0;

uint8_t buf2[bufferSize];
uint16_t i2=0;

WiFiUDP ntpUDP;
// more generic NTP server "europe.pool.ntp.org"
// time offset 3600 => 1 hour => Central European Time
// refresh time frequency 600000 => 10 minutes
NTPClient timeClient(ntpUDP, NTPserver, 3600, 600000);
const long ntpTimeCount = NTPTimeCount;
long ntpTimeCounter = 0;

void setup() {
  Serial.begin(UART_BAUD);
  delay(5000);                          //wait for STM32 to come up
  Serial.println("");                   //clear startup noise
  Serial.println("statusled 1");
  Serial.println("debug Booting");
  pinMode(switchGPIO, OUTPUT);
  client.enableOTA("admin", 8266); // Enable OTA (Over The Air) updates. Password defaults to MQTTPassword. Port is the default OTA port. Can be overridden with enableOTA("password", port).
  }

void onConnectionEstablished() {

  client.subscribe(subscribetopic, [] (const String &payload)  {
    Serial.println(""); // clear queue
    Serial.println(payload);
  });

  client.subscribe(subscribetopicswitch, [] (const String &payload)  {
    if(payload == "ON")
    {
      digitalWrite(switchGPIO, HIGH);
      client.publish(publishtopicswitch, "switch on");
    }
    else if(payload == "OFF")
    {
      digitalWrite(switchGPIO, LOW);
      client.publish(publishtopicswitch, "switch off");
    }
  });

  IPAddress ip = WiFi.localIP();
  char buffer[80];
  sprintf(buffer, "%s chip %x started version %s with IP %d.%d.%d.%d", client.getMqttClientName(), ESP.getChipId(), version, ip[0], ip[1], ip[2], ip[3]);
  
  client.publish(publishtopicstatus, buffer);

  Serial.println("debug Booting done.");
  Serial.print("debug ");
  Serial.println(buffer);
  server.begin(); // start TCP server 

  Serial.println("debug Connect to NTP server.");
  timeClient.forceUpdate();
  ReadAndDecodeTime(); //status led is set or reset here any way
}

void loop() {
  client.loop();    // WIFI and MQTT client

  if(ntpTimeCounter > ntpTimeCount){
    ntpTimeCounter = 0;
    ReadAndDecodeTime();
  } else {
    ntpTimeCounter++;
    delay(1);               //create a less random loop timing
  }

  // only serial bridge code below, which will restart the loop, if no client connected
  if(!UARTclient.connected()) { // if client not connected
    UARTclient = server.available(); // wait for it to connect
    return;
  }
  
  // here we have a connected client
  if(UARTclient.available()) {
    while(UARTclient.available()) {
      buf1[i1] = (uint8_t)UARTclient.read(); // read char from client
      if(i1<bufferSize-1) i1++;
    }
    // now send to UART:
    Serial.write(buf1, i1);
    i1 = 0;
  }

  if(Serial.available()) {

    // read the data until pause:
   
    while(1) {
      if(Serial.available()) {
        buf2[i2] = (char)Serial.read(); // read char from UART
        if(i2<bufferSize-1) i2++;
      } else {
        //delayMicroseconds(packTimeoutMicros);
        delay(packTimeout);
        if(!Serial.available()) {
          break;
        }
      }
    }
    
    // now send to WiFi:
    UARTclient.write((char*)buf2, i2);
    i2 = 0;
  }
}

void ReadAndDecodeTime() {
    int DayToEndOfMonth,DayOfWeekToEnd,DayOfWeekToSunday;
    int ThisDay,ThisMonth,ThisYear,DayOfW;
    int Dls;                    //DayLightSaving
    char buffer[60];

    //get a random server from the pool
    timeClient.update();

    // avoid sending the wrong time
    if(timeClient.isTimeSet()) {
     
      // now convert NTP time into everyday time:
      time_t ThisTime = timeClient.getEpochTime();
  
      //calculate actual day to evaluate the summer/winter time of day ligh saving
      DayOfW = weekday(ThisTime);
      ThisDay = day(ThisTime);
      ThisMonth = month(ThisTime);
    
      //check daylight saving
      Dls = 0;    //default winter time
      //From April to september we are surely on summer time
      if (ThisMonth > 3 && ThisMonth < 10) {
        Dls = 1;
      };
      //March, month of change winter->summer time, last Sunday of the month
      //March has 31 days so from 25 included on Sunday we can be in summer time
      if (ThisMonth == 3 && ThisDay > 24) {
        DayToEndOfMonth = 31 - ThisDay;
        DayOfWeekToSunday = 7 - DayOfW;
        if (DayOfWeekToSunday >= DayToEndOfMonth)
          Dls = 1;
      };
      //October, month of change summer->winter time, last Sunday of the month
      //October has 31 days so from 25 included on Sunday we can be in winter time
      if (ThisMonth == 10) {
        Dls = 1;
        if (ThisDay > 24) {
          DayToEndOfMonth = 31 - ThisDay;
          DayOfWeekToEnd = 7 - DayOfW;
          if (DayOfWeekToEnd >= DayToEndOfMonth)
          Dls = 0;
        };
      };
  
      //add one hour if we are in summer time
      if (Dls == 1)
        ThisTime += 3600;

      // calculate date again from ThisTime as this might change due to a change in the time
      DayOfW = weekday(ThisTime);
      ThisDay = day(ThisTime);
      ThisMonth = month(ThisTime);
      ThisYear = year(ThisTime) - 2000;
    
      // translate american weekday numbering (first day of week = sunday) to european weekday numbering (first day of week = monday)
      DayOfW--;
      if (DayOfW == 0) {
        DayOfW = 7;
      };
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

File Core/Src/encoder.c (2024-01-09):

/*
 * encoder.c
 *
 *  Created on: 23.12.2019
 *      Author: Martin
 */

#include "encoder.h"

volatile int EncoderSteps;

TIM_HandleTypeDef *htim_encoder;						//handle to address timer

void Encoder_Init(TIM_HandleTypeDef *handle_tim)
{
	htim_encoder = handle_tim;
	HAL_TIM_Encoder_Start(htim_encoder, TIM_CHANNEL_ALL);
}

void Encoder()
{
	static unsigned short OldCounter;
	static short Acceleration;
	static unsigned short Decay;
	unsigned short Counter = htim_encoder->Instance->CNT;
	short DeltaCounter;

	DeltaCounter = Counter - OldCounter;
	//handle warp around
	if (DeltaCounter > MaxChange)
	{
		// counter underflow
		DeltaCounter -= MaxCounter;
	}
	else if (DeltaCounter < -MaxChange)
	{
		// counter overflow
		DeltaCounter += MaxCounter;
	}

	//Measure the number of steps, introduce acceleration
	if (DeltaCounter != 0)
		{
		EncoderSteps += DeltaCounter;
		EncoderSteps += DeltaCounter * Acceleration / AccelerationScale;
		++Acceleration;
		}
	else if (Decay > 0)
		{
		--Decay;
		}
	else
		{
		Decay=startDecay;
		if (Acceleration)
			{
			--Acceleration;			//no new step, decrease acceleration
			}
		}

	OldCounter = Counter;
}

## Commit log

2021-03-28 Inital schematic and pin out
    [RGBW-Lampe Control.sch, RGBW-Lampe Power.sch, RGBW-Lampe.kicad_pcb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]
2021-06-05 first working version to control RGBW LED incl IR remote and debug output via serial port
2021-06-05 PCB version produced
    [RGBW-Lampe Control.sch, RGBW-Lampe Power.sch, RGBW-Lampe.kicad_pcb]
2021-06-05 fix warnings fix cancel standby status led
    [RC5.c, RGBW-Lampe.ioc, main.c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]
2022-05-02 added dynamic pin configuration for external brightness measurement
2022-12-27 added missing linker script update lib version remove dead terminal integration
    [RGBW-Lampe.ioc, main.c, main.h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]
2022-12-27 added persistence for settings and last brightness measured via sensor code compiles is untested with respect to persistence and brightness measurement.
2022-12-28 added missing init for sender mode
    [main.c]
2023-04-12 get maxbrightness from settings added commands switched adc to registration of callback fixed main.c
    [RC5.c, RGBW-Lampe.ioc, extbrightness.c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]
2023-04-14 added alarm logic for light and sound
    [sinewave.ods]
2023-04-15 fix and cleanup setbrightness.c set DAC DMA to circular
    [RGBW-Lampe.ioc, acousticdddsalarm.c, setbrightness.c]
2023-05-07 fix potential div by zero fix UART DMA settings upgrade STM32cube version
    [RGBW-Lampe.ioc, setbrightness.c]
2023-05-07 fixed external brightness measurement fixed terminal init fixed saving last brightness fixed commands adjusted settings
    [extbrightness.c, main.c, setbrightness.c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]
2023-05-09 included PWM offset in PWM wight calculation
2023-05-12 fix reception handler to process data outside of interrupt
    [main.c, settigscommands.c, terminal_helper.c]
2023-05-13 added initial WLAN code added command to control status LED
2023-05-19 fixed minor issues with acousticdddsalarm.c, bug stepcounter underflow still present
    [RGBW-Lampe.ioc, acousticdddsalarm.c, main.c]
2023-05-20 fix acoustic alarm with new less computational intensive approach
    [RGBW-Lampe.ioc, acousticdddsalarm.c, main.c]
2023-05-21 fix white space added files for mod light
    [main.c, mainmenu.c, setbrightness.c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]
2023-05-24 added initaial code fpr mood light - still buggy
    [mainmenu.c, setbrightness.c, settigscommands.c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]
2023-05-30 added timeout to alarm fix warnings in fadelight.h and settigscommands.c
    [settigscommands.c]
2023-05-31 switched from delay to pulse count via interrupt for RC5 Encoder bug no PWM signal from TIM10
    [RC5.c, RC5.h, RGBW-Lampe.ioc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]
2023-05-31 replace main callback with registered callbacks
    [RC5.c, RC5.h, main.c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]
2023-06-01 fix missing TIM10 output for RC5 encoder adjust RC5 pin and timing settings
    [RC5.c, RC5.h, RGBW-Lampe.ioc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]
2023-06-02 simplify RC5 encoder fix value in scaled sine table fix alarm sound start fix warnings added volume level control removed magic numbers
    [RC5.c, RC5.h, acousticdddsalarm.c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]
2023-06-10 minor code clean-up add missing array size
    [RC5.h, setbrightness.c]
2023-07-16 added debug command to terminal added address entry to RC5 encoder command in terminal
2023-09-19 first WLAN firmware with serial WLAN bridge, NTP client, and OTA interaction with STM32 firmware to be tested
2023-09-23 fix mutual reset signals between both MCU adjust presets ensure data from ESP8266 is received by STM32 by adding dealys after each data package
    [RGBW-Lampe.ioc, WLAN.ino, main.c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]
2023-09-24 added ESP reset fixed data loss in STM32 UART receiver code fixed light stayed on at power off when in light fading mode fix weekday numbering
    [WLAN.ino, mainmenu.c, settigscommands.c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]
2023-09-24 fix wrong date during day light saving at midnight.
    [WLAN.ino]
2023-09-26 fix alarm skipcount decrease improve color changing pattern to avoid low light situation
    [rtc.c]
2023-09-28 fix alarm skip count
    [rtc.c]
2023-10-07 fix missing time update when no client connected
    [WLAN.ino]
2023-10-08 added error code output from ESp for STM32
    [WLAN.ino]
2023-10-09 fix esp reset command add STM32 software version command removed delays after ESP send command via UART added command execute after every line termination
    [WLAN.ino, settigscommands.c, terminal_helper.c]
2023-10-09 remove unnecessary delay from sending via UART
2023-10-10 do not drive STM32 rst from ESP to avoid collision with STM32 debugger restart STM32 UART on error to handle ESP boot messages
    [WLAN.ino, terminal_helper.c]
2023-10-11 fix remote control from other lamp
    [RC5.c]
2023-11-01 fix alarm end when command send via terminal add MQTT support to WLAN code
    [WLAN.ino, settigscommands.c]
2023-11-04 added switch support and more status messages MQTT interface
2023-11-05 minor fix in terminal
    [settigscommands.c]
2023-11-12 externalized device settings minor improvements on debug output update time via NTP only once a day
2023-12-16 updated kicad version
    [RGBW-Lampe Control.kicad_sch, RGBW-Lampe Power.kicad_sch, RGBW-Lampe.kicad_pcb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]
2023-12-25 fix encoder
2024-01-09 remove dead code and fix brightness settings
    [encoder.c, setbrightness.c]
2024-04-28 update CUBE MX version fix RC5 sender: duty cycle and toggle bit
    [RC5.c, RC5.h, RGBW-Lampe.ioc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]

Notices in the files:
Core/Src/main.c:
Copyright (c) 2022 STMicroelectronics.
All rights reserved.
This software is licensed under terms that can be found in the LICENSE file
